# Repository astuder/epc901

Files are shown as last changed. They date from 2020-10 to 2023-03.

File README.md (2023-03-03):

# Introduction
The [ESPROS epc901](https://www.espros.com/photonics/epc901/) is a CCD line sensor with a resolution of 1024 monochrome pixels.

Compared to other image sensors the epc901 is very easy to drive, requiring only one voltage, I2C, a few digital I/Os and an ADC. It is also available for [$33 in single units from Digi-key](https://www.digikey.com/en/products/detail/espros-photonics-ag/EPC901-CSP32-033/10516882). On the downside, the sensor
comes in a BGA package, the evaluation kit is [very expensive at $1400](https://www.digikey.com/en/products/detail/espros-photonics-ag/EPC901-EVALUATION-KIT-V1/10516848),
and we haven't seen this sensor from any other distributors than Digi-key.

This repository contains design files to build hardware and software to interact with the sensor. 

For Windows users, there's now also a [version of g3gg0.de SpectrumPlotter](https://github.com/astuder/epc901SpectrumPlotter) adapted to work with my epc901 firmware.

@fmilburn3 posted a write-up of this project and a few spectroscopy experiments on [element14](https://www.element14.com/community/community/project14/sensors/blog/2020/11/11/spectrography-using-the-epc901-high-speed-line-image-sensor).

## Table of contents

[Hardware](#hardware)
* [Breakout board](#breakout-board)
  * [Connector pinout](#connector-pinout)
  * [Jumpers](#jumpers)
  * [Config resistor array](#config-resistor-array)
  * [Physical dimensions](#physical-dimensions)
  * [Lens holder & lens](#lens-holder--lens)
* [Adapter board](#adapter-board)
  * [Pin mapping](#pin-mapping)
  * [Jumpers](#jumpers)
* [Shared](#shared)
* [Spectroscope tube](#spectroscope-tube)

[Software](#software)
* [Firmware](#firmware)
  * [Shell](#shell)
  * [Capture logic](#capture-logic)
  * [Trigger logic](#trigger-logic)
  * [Transfer format](#transfer-format)
* [Python](#python)
  * [epc901camera.py](#epc901camerapy)
  * [example scripts](#example-scripts)
 
[License](#license)

# Hardware

All hardware in this project is designed with KiCad version 5.1.6.

The hardware consists of a breakout board for the image sensor, and an adapter board for vertically mounting the breakout board on an ST Nulceo-144 development board.

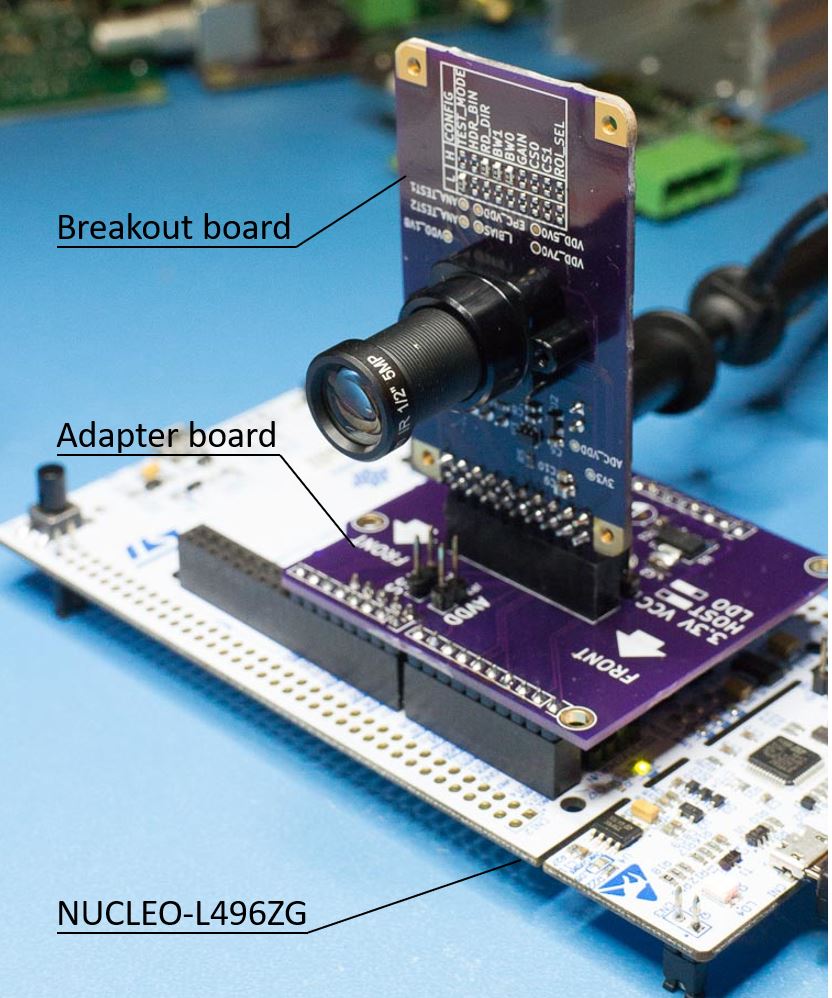
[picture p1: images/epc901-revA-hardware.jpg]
Breakout and adapter boards mounted on a NUCLEO L496ZG


## Breakout board

The folder [```./hardware/breakout```](./hardware/breakout) contains the KiCad project for the epc901 breakout board.

The image sensor comes in a 2x16, 0.5 mm pitch BGA package and looks very fragile. With careful handling and placement, we successfully assembled a few boards
using a stainless steel solder stencil and an unmodified toaster oven for reflow. Reflow on a hotplate probably works as well.

In addition to the image sensor and related passives, the breakout board also integrates an ADC. Footprint and firmware are compatible with [Texas Instruments ADCS7476](https://www.ti.com/product/ADCS7476) and [Analog Devices AD7476](https://www.analog.com/en/products/ad7476.html) which are 1 MSPS 12-bit ADCs with SPI-like interface.

The PCB can be ordered from OSH Park using this [link](https://oshpark.com/shared_projects/5eUl3QVW).

### Connector pinout

Pin|Function|Comment
-|-|-
1|GND|digital ground
2|PWR_DOWN|see epc901 datasheet
3|DATA_RDY|see epc901 datasheet
4|CLR_DATA|see epc901 datasheet
5|SHUTTER|see epc901 datasheet
6|CLR_PIX|see epc901 datasheet
7|GNDA|analog ground
8|VIDEO_P|positive video signal for use w/ external ADC, see epc901 datasheet
9|VIDEO_N|negative video signal for use w/ external ADC, see epc901 datasheet
10|GNDA|analog ground
11|GND|digital ground
12|ADC_CLK|SPI clk to on-board ADC
13|ADC_DATA|SPI data from on-board ADC
14|ADC_CS|SPI chip select for on-board ADC
15|GND|digital ground
16|3V3|3.3V power supply
17|GND|digital ground
18|READ|see epc901 datasheet
19|SDA|I2C data
20|SCL|I2C clock

### Jumpers

ID|Function|Comment
-|-|-
JP1|STAR GND|Star ground point between GND and GNDA. Close to connect, leave open if GNDA and GND are connected off-board.
JP2|ADC SELECTION|Selects whether to use the on-board ADC or an external ADC. External ADC will route VIDEO_P to pin 8 in the connector.

### Config resistor array

These resistors control the configuration of the image sensor on power-up. For details, see sections 4, 7.1 and 12 in the epc901 datasheet.

### Physical dimensions

The size of the board is 61 x 36 mm. The mounting holes in the corners are spaced 55 x 30 mm and have a diameter of 2.2 mm, designed for M2 screws.

The mounting holes for the lens holder are located 29 mm from the left board edge and 8 mm from top and bottom board edge. They have a diameter of 2.2 mm, designed for M2 screws.

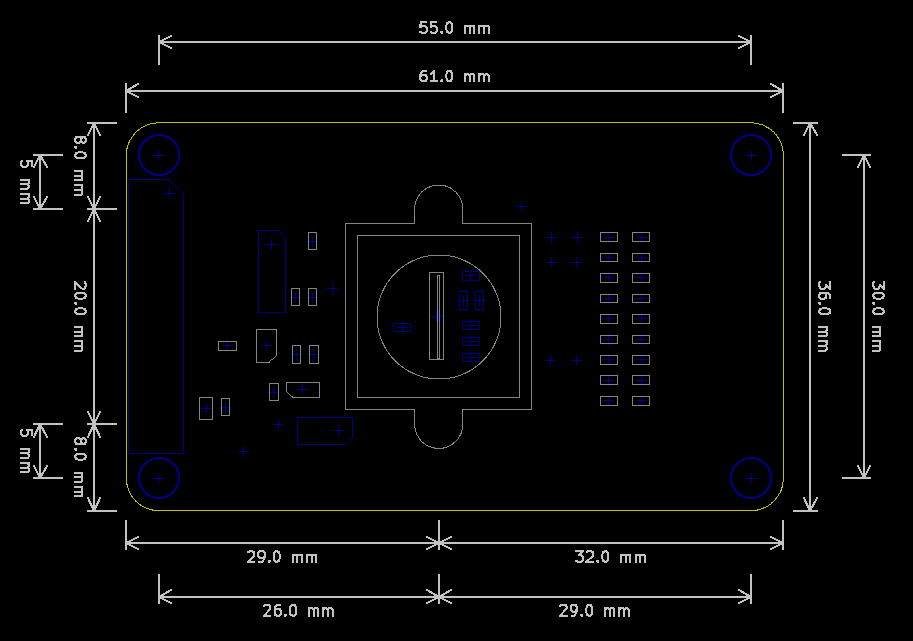
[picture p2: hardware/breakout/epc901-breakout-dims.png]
epc901-breakout dimensions


### Lens holder & lens

The breakout board has space and mounting holes for a lens holder. The spacing between the mounting holes is 20mm. For full coverage, the lens should support 1/2.3" or larger sensors.

For our prototypes, we chose a [M12 metal lens holder w/ 20mm hole spacing](https://www.m12lenses.com/CNC-Machined-M12-Lens-Holder-Metal-p/pt-lh031m.htm) and a [25mm M12 lens for 1/2" sensors](https://www.m12lenses.com/25mm-F2-4-5MP-CCTV-Lens-p/pt-2524mp5y.htm). In the US, a wide selection of lens holders and lenses can be found at [M12 Lenses Inc](https://www.m12lenses.com).

For use in a spectrograph, a lens may not be required. However we recommend protecting the sensor against accidental physical damage with some sort of bracket or baffel.

## Adapter board

The folder [```./hardware/adapter-shield```](./hardware/adapter-shield) contains the KiCad project for an adapter to mount the 
epc901 breakout board on the NUCLEO evaluation board.

The layout of the adapter board follows the Arduino Shield standard. This means you could mount the adapter and sensor breakout board on any compatible MCU board. Though
you will likely have to adapt the firmware to make it work.

The PCB can be ordered from OSH Park using this [link](https://oshpark.com/shared_projects/md99YXCX).

### Pin mapping

|Arduino|Nucleo|L496ZG|Breakout|Comment
|-|-|-|-|-
|+3V3|CN8 7|+3V3||Connected to JP1.
|+5V|CN8 9|+5V||Connected to 3.3V LDO.
|GND|CN8 11|GND|GND|
|GND|CN8 13|GND|GND|
|D0|CN10 16|PD9|PWR_DOWN|
|D1|CN10 14|PD8|DATA_RDY|
|D2|CN10 12|PF15|CLR_DATA|
|D3|CN10 10|PE13|SHUTTER|Controlled by TIM1_CH3.
|D4|CN10 8|PF14|CLR_PIX|
|D9|CN7 18|PD15|READ|
|D10|CN7 16|PD14|ADC_CS|
|D12/MISO|CN7 12|PA6|ADC_DATA|
|D13/SCK|CN7 10|PA5|ADC_CLK|
|GND|CN7 8|GND|GND|
|A0|CN9 1|PA3|VIDEO_P|
|A1|CN9 3|PC0|VIDEO_N|
||CN10 1|AVDD||Connected to JP3, reserved to supply analog power from Nucleo in future revisions.
||CN10 3|AVSS||Connected to JP4, alternative source for analog ground from Nucleo.
||CN10 5|GND|GND|
||CN10 7|PB1|VIDEO_P|Alternative analog pins for use with AVDD and AVSS connection in future revisions.
||CN10 9|PC2|VIDEO_N|Alternative analog pins for use with AVDD and AVSS connection in future revisions.

### Jumpers

ID|Function|Comment
-|-|-
JP1|3.3V VCC|Select between LDO on adapter or Nucleo (HOST) as source for 3.3V power supply to breakout board.
JP2|* GND|Star ground point between GND and GNDA. Close to connect, leave open if GNDA and GND are connected on breakout board.
JP3|AVDD|Reserved for future use to supply power to VDD_OA of the EPC901 from the Nucleo.
JP4|AVSS|Star ground point between analog ground of the breakout board and analog ground of the Nucleo. May be useful when using the ADCs of the STM32.

## Shared

The folder [```./hardware/shared```](./hardware/shared) contains custom KiCad symbols, footprints and 3d models that can be reused across KiCad projects in this repository.

## Spectroscope tube

For spectroscopy experiments we created a tube to mount an optical slit and difraction grating. The 3D model is available in the folder [```./hardware/spectroscope-tube```](./hardware/spectroscope-tube).

# Software

## Firmware

The folder [```./software/breakout```](./software/breakout) contains the firmware to control the epc901 breakout board with an
STM32L4 using the [NUCLEO-L496ZG evaluation board](https://www.digikey.com/en/products/detail/stmicroelectronics/NUCLEO-L496ZG/6697037). This specific MCU and
evaluation board were chosen because we had one laying around.

The firmware is developed and built with the latest version of STM32CubeIDE (version 1.4.2 as of October 2020). To import the project into STM32CubeIDE, clone this
repository, open STM32CubeIDE and import the project with ```File > Open Project From File System..```, and select the folder ```./software/breakout```. Follow the standard
procedure for building the firmware and programming the NUCLEO evaluation board.

### Shell

The firmware exposes a command shell over serial. The parameters of the serial connection are 115200 8N1.

Preceding a command with @ will suppress local echo and command prompt, which is useful when developing an application that interacts with the shell.

Most commands that configure an aspect of the firmware return the current setting if no value is provided. For example ```exposure``` will return the currently configured exposure time.

|Command|Description|
|-|-|
|help|Display list of available commands.|
|help COMMAND|Display help text for command.|
|echo ON/OFF|Turn local echo on or off.|
|regread REGISTER|Read register of image sensor over I2C.|
|regwrite REGISTER VALUE|Write to value to register of image sensor over I2C.|
|reset mcu|Reset the STM32 microcontroller.|
|reset camera|Reset the camera settings, for example exposure or burst, to their defaults.|
|reset sensor|Software reset of the image sensor through I2C.|
|exposure TIME_US|Set exposure time in microseconds.|
|exposure max|Get maximum exposure time supported.|
|capture|Start capture using the configured settings.|
|capture abort|If there's a capture in progress, abort current capture.|
|transfer|read next image from the frame buffer.|
|transfer all|read all images available in the frame buffer.|
|transfer last|read last image from frame buffer, all other images will be discarded.|
|burst ON/OFF|turn burst mode on or off.|
|burst fast|Turn on burst mode with fast capture, where image capture and data read out overlap. This can result in noisier data than regular burst mode.|
|burst frames COUNT|Set number of frames to capture in a burst.|
|burst interval TIME_MS|Set interval in milliseconds at which frames are captured. 0 will capture frames at the maximum speed possible.|
|trigger ON/OFF|Enable or disable trigger.|
|trigger source EXTERNAL/LEVEL/ZONE|Select source of trigger signal.|
|trigger direction RISING/FALLING|Set which direction of a signal will trigger. for ```level``` and ```zone``` rising means above/inside level/zone, falling means NOT above/inside.|
|trigger level LEVEL|Set trigger level for ```level``` trigger source.|
|trigger zone X1 Y1 X2 Y2|Set trigger zone defined by two corners for ```zone``` trigger source.|

### Capture logic

The ```capture``` command will start the image capture process based on the configuration of the camera.

First the firmware checks if there's enough space in the frame buffer for the configured number of frames (1 or burst frames). An error will be returned if there is not enoug space.

Next, if ```trigger``` is enabled, the camera waits until the configured trigger condition is met. 

Next, image capture starts. If ```burst``` is enabled, it will capture the configured number of frames. All frames captured are stored in a frame buffer. 

After the capture process is complete, images can be read from the frame buffer with the ```transfer``` command.

The shell will respond with ```BUSY``` if the camera is waiting for a trigger or a single image capture or burst is in progress. At any time, the command ```capture abort``` will return the camera back to idle state.

### Trigger logic

**External**

The external trigger source is wired to pin D35/PB11 and the USER button (B1).

Trigger direction ```rising``` triggers when the signal changes from low to high, or when the button is pressed down.
Trigger direction ```falling``` triggers when the signal changes from high to low, or when the button is released.

**Level**

The level trigger source uses live sensor data to trigger. When starting capture, the firmware will continously capture images until the trigger condition is met or capture is aborted.

Trigger direction ```rising``` triggers when a pixel is on or above the configured trigger level.
Trigger direction ```falling``` triggers when no pixel is on or above the configured trigger level.

**Zone**

The zone trigger source uses live sensor data to trigger. When starting capture, the firmware will continously capture images until the trigger condition is met or capture is aborted.

Trigger direction ```rising``` triggers when a pixel is inside the configured trigger zone.
Trigger direction ```falling``` triggers when no pixel is inside the configured trigger zone.

### Transfer format

The ```transfer``` command reads images from the frame buffer and sends them over serial. Each image is sent in two chuncks, each terminated with a linefeed. 

1. Frame metadata seperated with commas: frame number, time in milliseconds since first frame, exposure time in microseconds, number of pixels in frame
2. Frame data: a continous string with one 3-character hexadecimal number per pixel representing the brightness value

## Python

The folder [```./software/python```](./software/python) contains a Python library that wraps the shell of the
firmware, and a few useful Python scripts that use the library.

### epc901camera.py

The Python library ```epc901camera.py``` wraps the shell exposed by the firmware into an API that's easy to use from Python. 

```
from epc901camera import Camera
camera = Camera()
camera.open("my serial port")
camera.setExposure(1000)
camera.capture()
pixels = camera.getPixels()
camera.close()
```

You can use ```sendCommand()``` to directly interact with the shell, which can be useful for operations that are not supported by the library yet. The following snippet writes to I2C registers of the sensor to increase the gain.
```
camera.sendCommand("regwrite 2 0x99")  # turn on config via regs
camera.sendCommand("regwrite 0 0x19")  # 4x gain, read-out direction same as set by resistor
```

See [example scripts](#example-scripts) for more details.

### example scripts

There are three scripts to interact with the breakout board:
* ```live.py``` displays output of the image sensor in realtime
* ```snap.py``` captures one image
* ```burst.py``` captures a series of images in a burst

The scripts are controlled with shared and a few unique command line arguments.
|Argument|```live.py```|```snap.py```|```burst.py```|Description|
|-|-|-|-|-|
|-h, --help|:heavy_check_mark:|:heavy_check_mark:|:heavy_check_mark:|Display help text.|
|-p PORT|:heavy_check_mark:|:heavy_check_mark:|:heavy_check_mark:|Serial port which connects to the camera board, this is the only required argument.|
|-e EXPOSURE|:heavy_check_mark:|:heavy_check_mark:|:heavy_check_mark:|Set exposure time in microseconds. If not specified, the default exposure time is 1ms (1000us).|
|-t {external,level,zone}||:heavy_check_mark:|:heavy_check_mark:|Enable trigger and select trigger source. See [Trigger logic](#trigger-logic).|
|-tdir {falling,rising}||:heavy_check_mark:|:heavy_check_mark:|Set direction of trigger logic.|
|-tl TRIG_LEVEL||:heavy_check_mark:|:heavy_check_mark:|Set brightness for level trigger. Valid values are 0-4095.|
|-tz x1,y1,x2,y2||:heavy_check_mark:|:heavy_check_mark:|Define rectangle for zone trigger. Valid x values are 0-1023, valid y values are 0-4095.|
|-td TRIG_DELAY||:heavy_check_mark:|:heavy_check_mark:|Set delay in milliseconds after trigger event before image capture starts.|
|-f FRAMES|||:heavy_check_mark:|Number of frames to capture in a burst.|
|-i INTERVAL|||:heavy_check_mark:|Set time interval in milliseconds between frames. 0 means best effort, i.e. at maximum speed possible. As it takes 1.3ms to read out a frame, effective capture rates may be lower than the configured interval. |
|-fast|||:heavy_check_mark:|Enable special burst mode where frames are read out of the sensor while the next exposure is captured. This may increase noise, but will increase effective burst speeds.|
|-gq||:heavy_check_mark:|:heavy_check_mark:|Don't display graph window.|
|-g GRAPH_TYPE|||:heavy_check_mark:|Display animated 2D graph or 3D surface plot. If argument is missing, no graph will be displayed.|
|-gc COLOR|||:heavy_check_mark:|Select alternative color map for 3D graph.|
|-gpng GRAPH_FILE||:heavy_check_mark:|:heavy_check_mark:|Save graph as PNG file.|
|-png PNG_FILE||:heavy_check_mark:|:heavy_check_mark:|Save sensor data as a gray-scale bitmap in a PNG file.|
|-csv CSV_FILE||:heavy_check_mark:|:heavy_check_mark:|Save sensor data as CSV file.|
|-a|:heavy_check_mark:|:heavy_check_mark:|:heavy_check_mark:|Automatically scale vertical axis of graphs based on image data. If not specified, the Y axis will go from 0 to 3000.|
|-sx px1,w1,px2,w2|:heavy_check_mark:|:heavy_check_mark:|:heavy_check_mark:|Scale labels of horizontal axis of 2D graphs by linear interpolation based on two points, for example to reflect wavelengths in a spectrograph. If not specified, the X axis will be labelled with pixel positions 0-1024.|

# License

Unless stated otherwise, all software in this project is licensed under the terms of MIT License.

The main exception are files imported from the STM32 SDK ([```./software/breakout/Drivers```](./software/breakout/Drivers)), and a few files
auto-generated by STM32CubeIDE. See source code for applicable license terms.

All hardware in this project is licensed under the terms of CERN Open Hardware Licence Version 2 - Permissive.

See [LICENSE-SW](LICENSE-SW) and [LICENSE-HW](LICENSE-HW) for additional details.

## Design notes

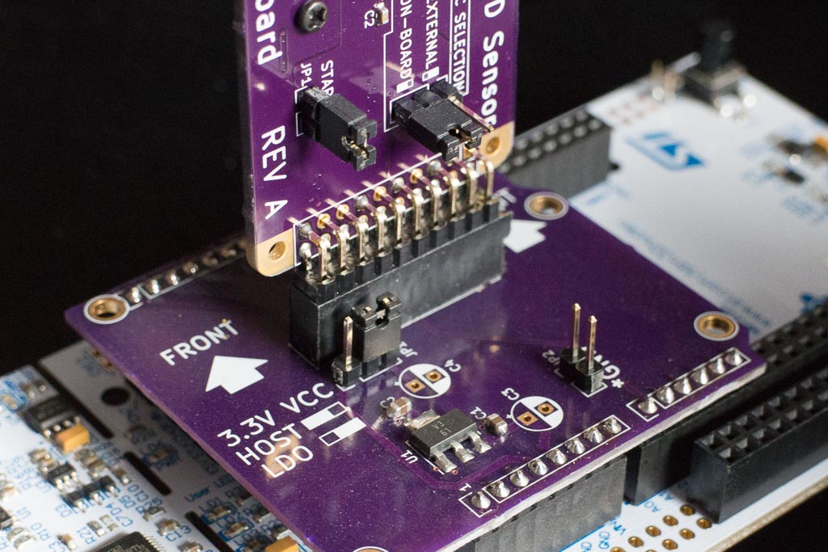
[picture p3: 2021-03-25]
images/epc901-revA-hardware-rear.jpg

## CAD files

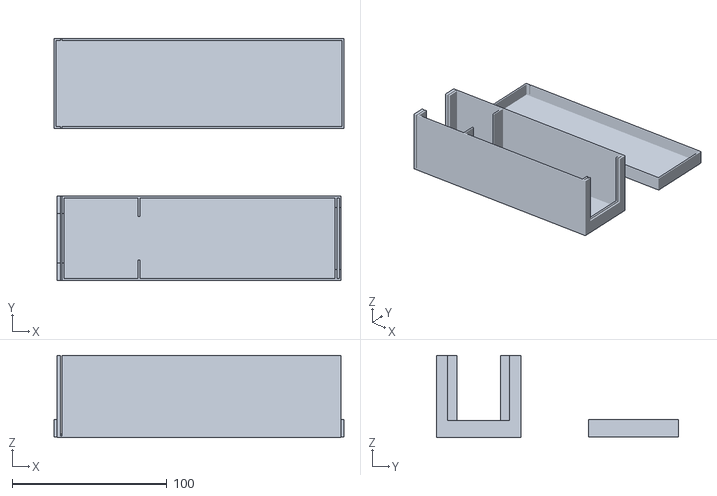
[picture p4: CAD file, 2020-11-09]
hardware/spectroscope-tube/Spectroscope_Tube_180mm.stl
187.2 x 156.2 x 53.2

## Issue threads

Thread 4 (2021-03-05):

Question convert to teensy and bbb

evermore99, 2021-03-05:
Hello first of all thanks for such a great project!

looking forward to replicate!

however I had a question: how hard is it to replace the nucleo with a teensy4.0? it runs way faster, is there a way you could come in contact with me?

i believe the bbb allows for python to run on it.

Could you send Me an email?

 Many thanks!

astuder, 2021-03-05:
Thanks for your interest in my project :)

Porting to the Teensy would require to rewrite the code that interacts with the STM32 HAL and hardware registers. Most of that is contained in EPC901.cpp, Leds.cpp, ShellPlatform.cpp and main.c. More work may be required if you want to integrate with the Teensy Arduino framework.

The speed of the MCU is not the limiting factor in this project. The ADC I used has a sampling rate of 10 MSPS, which translates to roughly 1000 fps maximum frame rate. For a higher speed version of the circuit see this project:
https://github.com/gregdavill/advent-calendar-of-circuits-2020/tree/main/syzygy-epc901
Though I don't think Greg started on the software (FPGA) side yet.

You can find my email address on my Github profile page.

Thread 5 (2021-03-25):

Question about jumpers

Sam2R, 2021-03-25:
Hi astuder,
First I wanted to thank you for your amazing work in this project. I had a question about the adapter shield. in your photo of the board I can see that you did not mount C3 and C4 capacitors on the shield so that means 5v connection on the board is ignored. Is that ok to use the board like you did (not mounting C3/C4 on shield and connect pins 1&2 on JP1 )?
in general, that would be helpful if you could mention default jumper connections on breakout and shield .
I appreciate very much your help on this and thanks again!

astuder, 2021-03-25:
Always happy when my projects are of interest to someone :)

I added the footprints for bigger caps just in case. The 5V LDO works fine with just the 1uF caps. I did only briefly check that the camera works when powered from 3V3 or 5V, but never investigated in depth whether one or the other is better, or whether more power supply filtering is needed.

I just uploaded an image showing the back side of the shield.
https://github.com/astuder/epc901/blob/main/images/epc901-revA-hardware-rear.jpg

astuder, 2021-03-25:
Clarification: I meant HOST (i.e. 3.3V from the Nucleo board) or LDO (i.e. 5V from the Nucleo down-converted to 3.3V)

Sam2R, 2021-03-25:
That's cool! Thanks, I'm happy you are  there I can ask my questions  👍
Wish me lock by the way I'm going to reflow/solder this tiny fragile EPC901 :)

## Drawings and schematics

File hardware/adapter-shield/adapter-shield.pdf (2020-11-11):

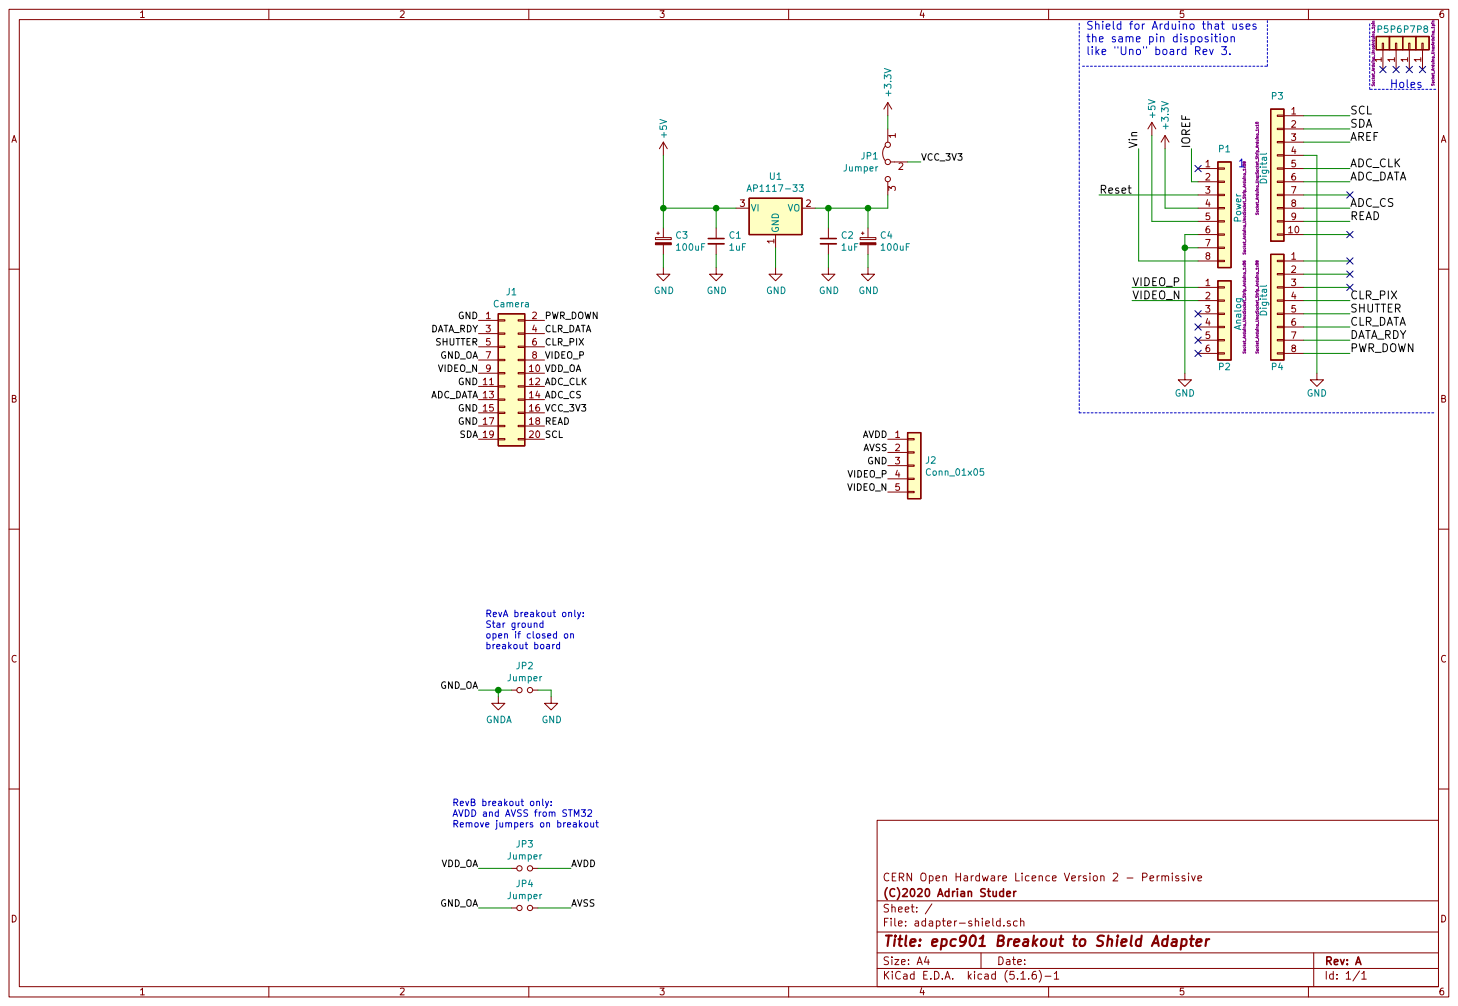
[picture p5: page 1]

Shield for Arduino that uses
the same pin disposition
VCC_3V3 VIDEO_N

Star ground
open if closed on
breakout board RevB breakout only: AVDD and AVSS from STM32 Remove jumpers on breakout
VDD_OA GND_OA GND_OA

Jumper
CERN Open Hardware Licence Version 2 - Permissive JP4

File: adapter-shield.sch Sheet: / (C)2020 Adrian Studer

Id: 1/1 Title: epc901 Breakout to Shield Adapter

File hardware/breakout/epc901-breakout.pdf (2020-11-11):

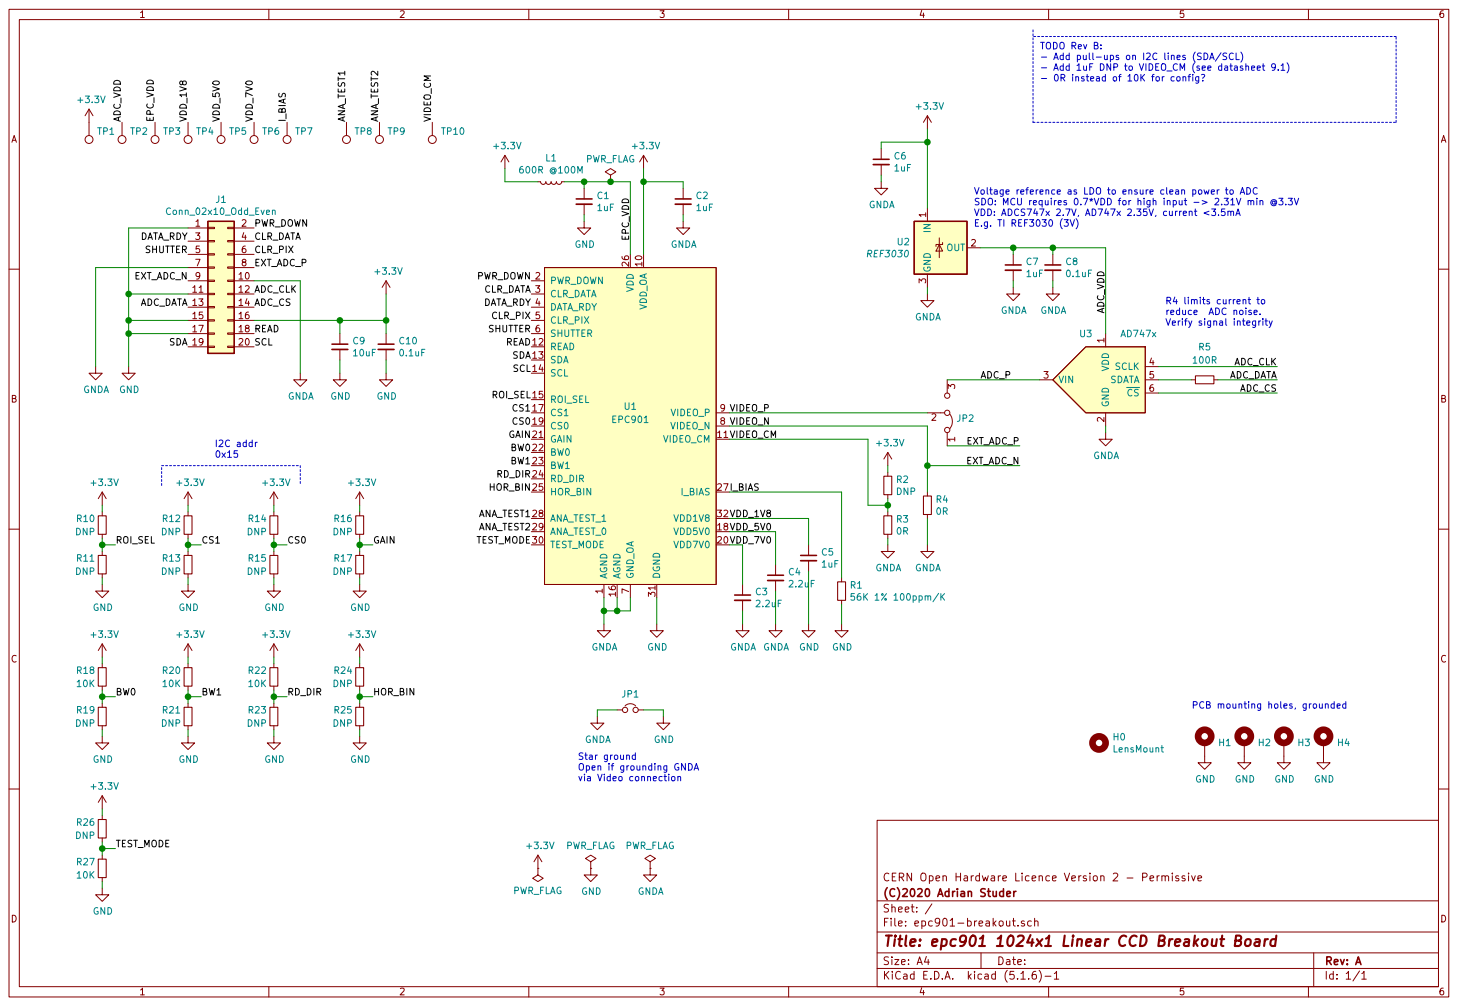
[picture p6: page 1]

TODO Rev B: - Add pull-ups on I2C lines (SDA/SCL)

- Add 1uF DNP to VIDEO_CM (see datasheet 9.1)
- 0R instead of 10K for config?

SDO: MCU requires 0.7*VDD for high input -> 2.31V min @3.3V
VDD: ADCS747x 2.7V, AD747x 2.35V, current <3.5mA
E.g. TI REF3030 (3V)

1 VDD_OA 10 VIDEO_CM 11 READ 12 SDA 13 SCL 14 ROI_SEL 15 AGND 16 CS1 17 VDD5V0 18 CS0 19 PWR_DOWN 2 VDD7V0 20 GAIN 21 BW0 22 BW1 23 RD_DIR 24 HOR_BIN 25 VDD 26

reduce ADC noise. Verify signal integrity

17 | 18
19 | 20

2 VIN 3 SCLK 4 SDATA 5 CS 6 U3 AD747x R4

PCB mounting holes, grounded

Star ground
Open if grounding GNDA
via Video connection

File: epc901-breakout.sch Sheet: / (C)2020 Adrian Studer

Id: 1/1 Title: epc901 1024x1 Linear CCD Breakout Board

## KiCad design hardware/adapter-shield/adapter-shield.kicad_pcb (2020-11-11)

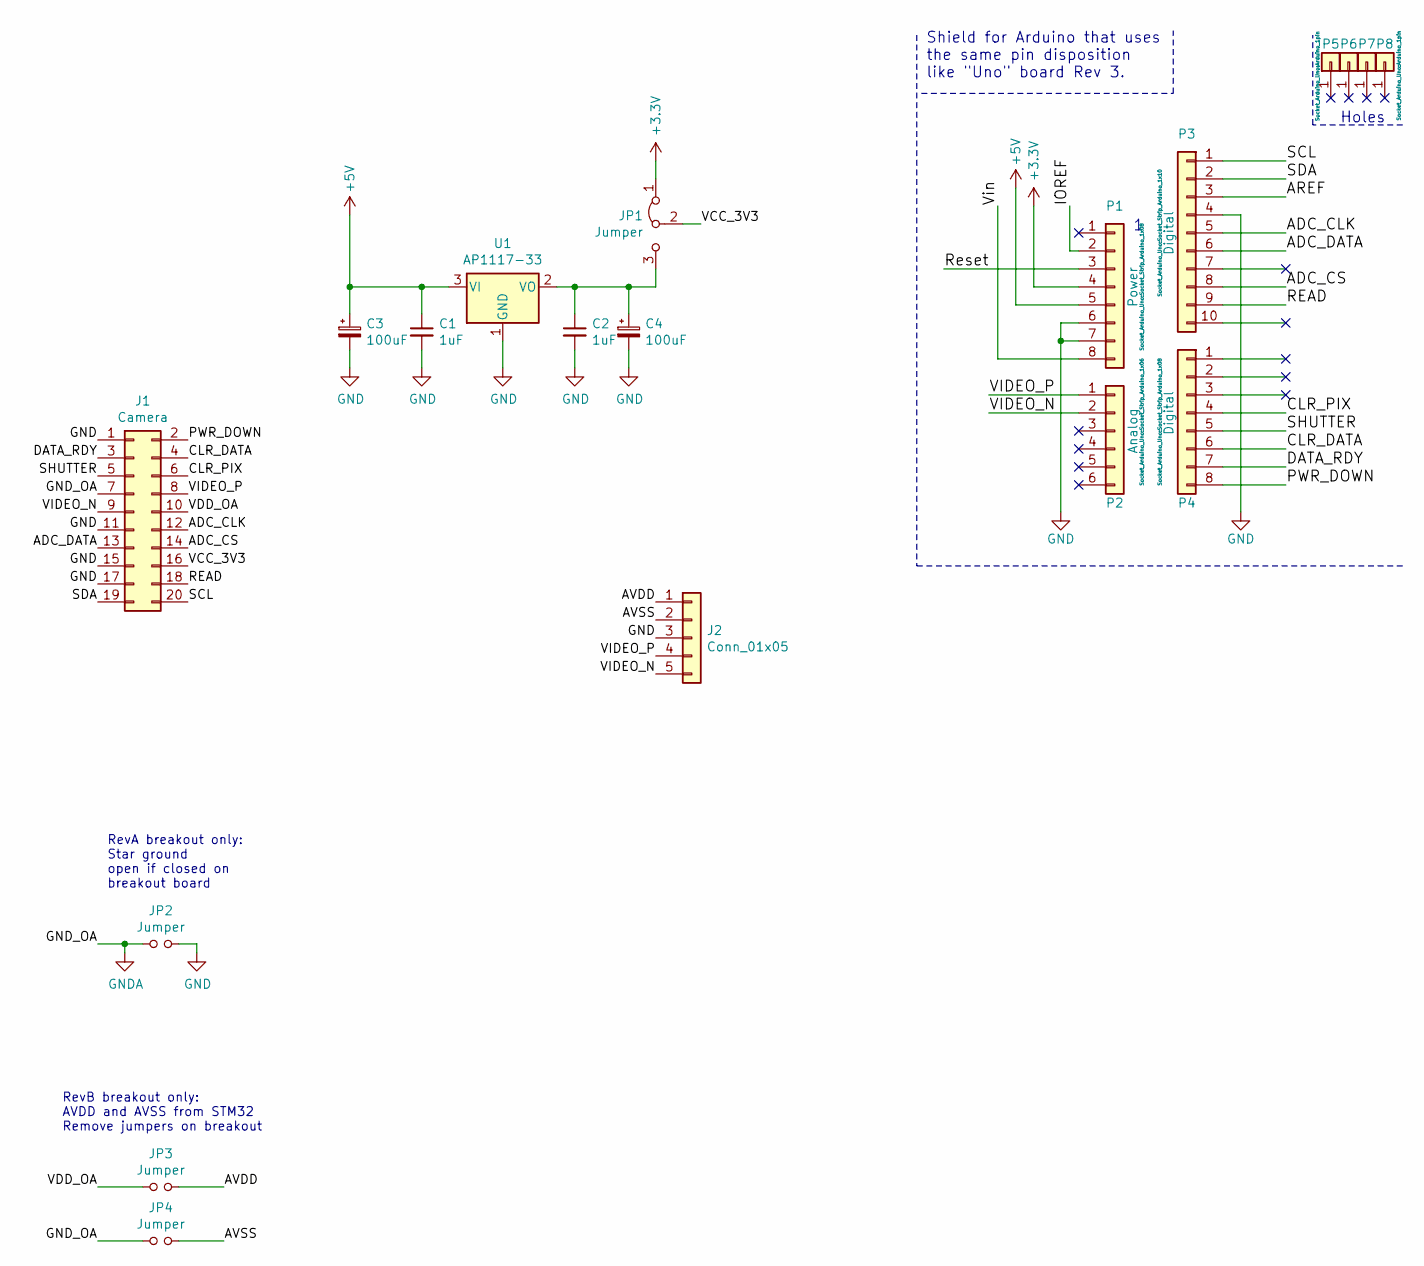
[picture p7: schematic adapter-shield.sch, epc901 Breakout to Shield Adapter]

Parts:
C1, C2: 1uF; C_0805_2012Metric
C3, C4: 100uF; CP_Radial_D5.0mm_P2.50mm
J1: Camera; PinSocket_2x10_P2.54mm_Vertical
J2: Conn_01x05; PinHeader_1x05_P2.54mm_Vertical
JP1: Jumper; PinHeader_1x03_P2.54mm_Vertical
JP2, JP3, JP4: Jumper; PinHeader_1x02_P2.54mm_Vertical
P1: Power; Socket_Strip_Arduino_1x08
P2: Analog; Socket_Strip_Arduino_1x06
P3: Digital; Socket_Strip_Arduino_1x10
P4: Digital; Socket_Strip_Arduino_1x08
P5, P6, P7, P8: CONN_01X01; Arduino_1pin
U1: AP1117-33; SOT-223-3_TabPin2

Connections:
+3V3: JP1.1 (A), P1.4
+5V: C1.1, C3.1, P1.5, U1.3 (VI)
/ADC_CLK: J1.12, P3.5
/ADC_CS: J1.14, P3.8
/ADC_DATA: J1.13, P3.6
/AREF: P3.3
/AVDD: J2.1, JP3.2
/AVSS: J2.2, JP4.2
/CLR_DATA: J1.4, P4.6
/CLR_PIX: J1.6, P4.4
/DATA_RDY: J1.3, P4.7
/IOREF: P1.2
/PWR_DOWN: J1.2, P4.8
/READ: J1.18, P3.9
/Reset: P1.3
/SCL: J1.20, P3.1
/SDA: J1.19, P3.2
/SHUTTER: J1.5, P4.5
/VCC_3V3: J1.16, JP1.2 (C)
/VDD_OA: J1.10, JP3.1
/VIDEO_N: J1.9, J2.5, P2.2
/VIDEO_P: J1.8, J2.4, P2.1
/Vin: P1.8
GND: C1.2, C2.2, C3.2, C4.2, J1.1, J1.11, J1.15, J1.17, J2.3, JP2.2, P1.6, P1.7, P3.4, U1.1 (GND)
GNDA: J1.7, JP2.1, JP4.1
unnamed: C2.1, C4.1, JP1.3 (B), U1.2 (VO)

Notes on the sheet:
Holes
Shield for Arduino that uses the same pin disposition like "Uno" board Rev 3.
RevA breakout only: Star ground open if closed on breakout board
RevB breakout only: AVDD and AVSS from STM32 Remove jumpers on breakout

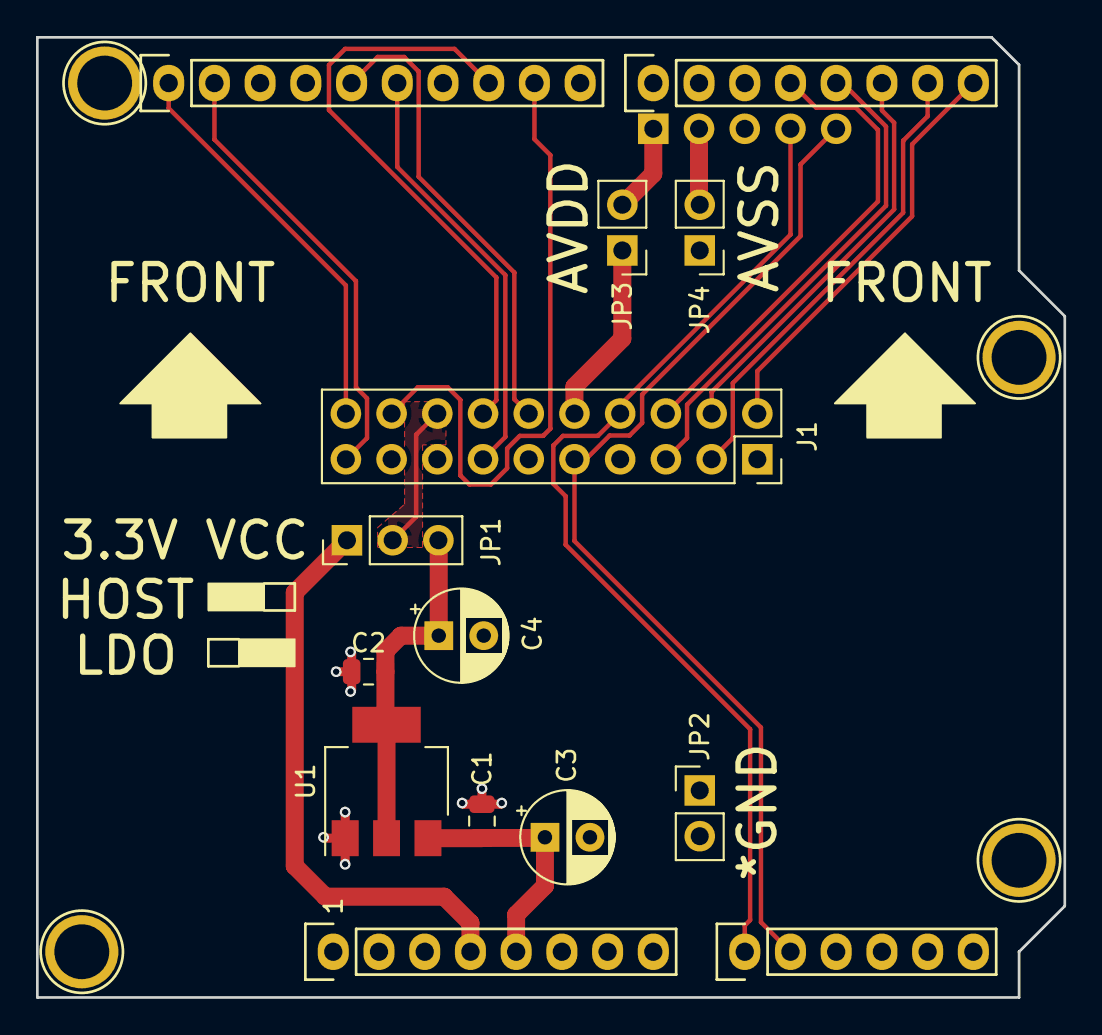
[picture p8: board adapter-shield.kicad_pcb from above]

Board: 2 copper layers, 57.1 x 53.3 mm, 19 parts (1 on the bottom side), 22 nets.

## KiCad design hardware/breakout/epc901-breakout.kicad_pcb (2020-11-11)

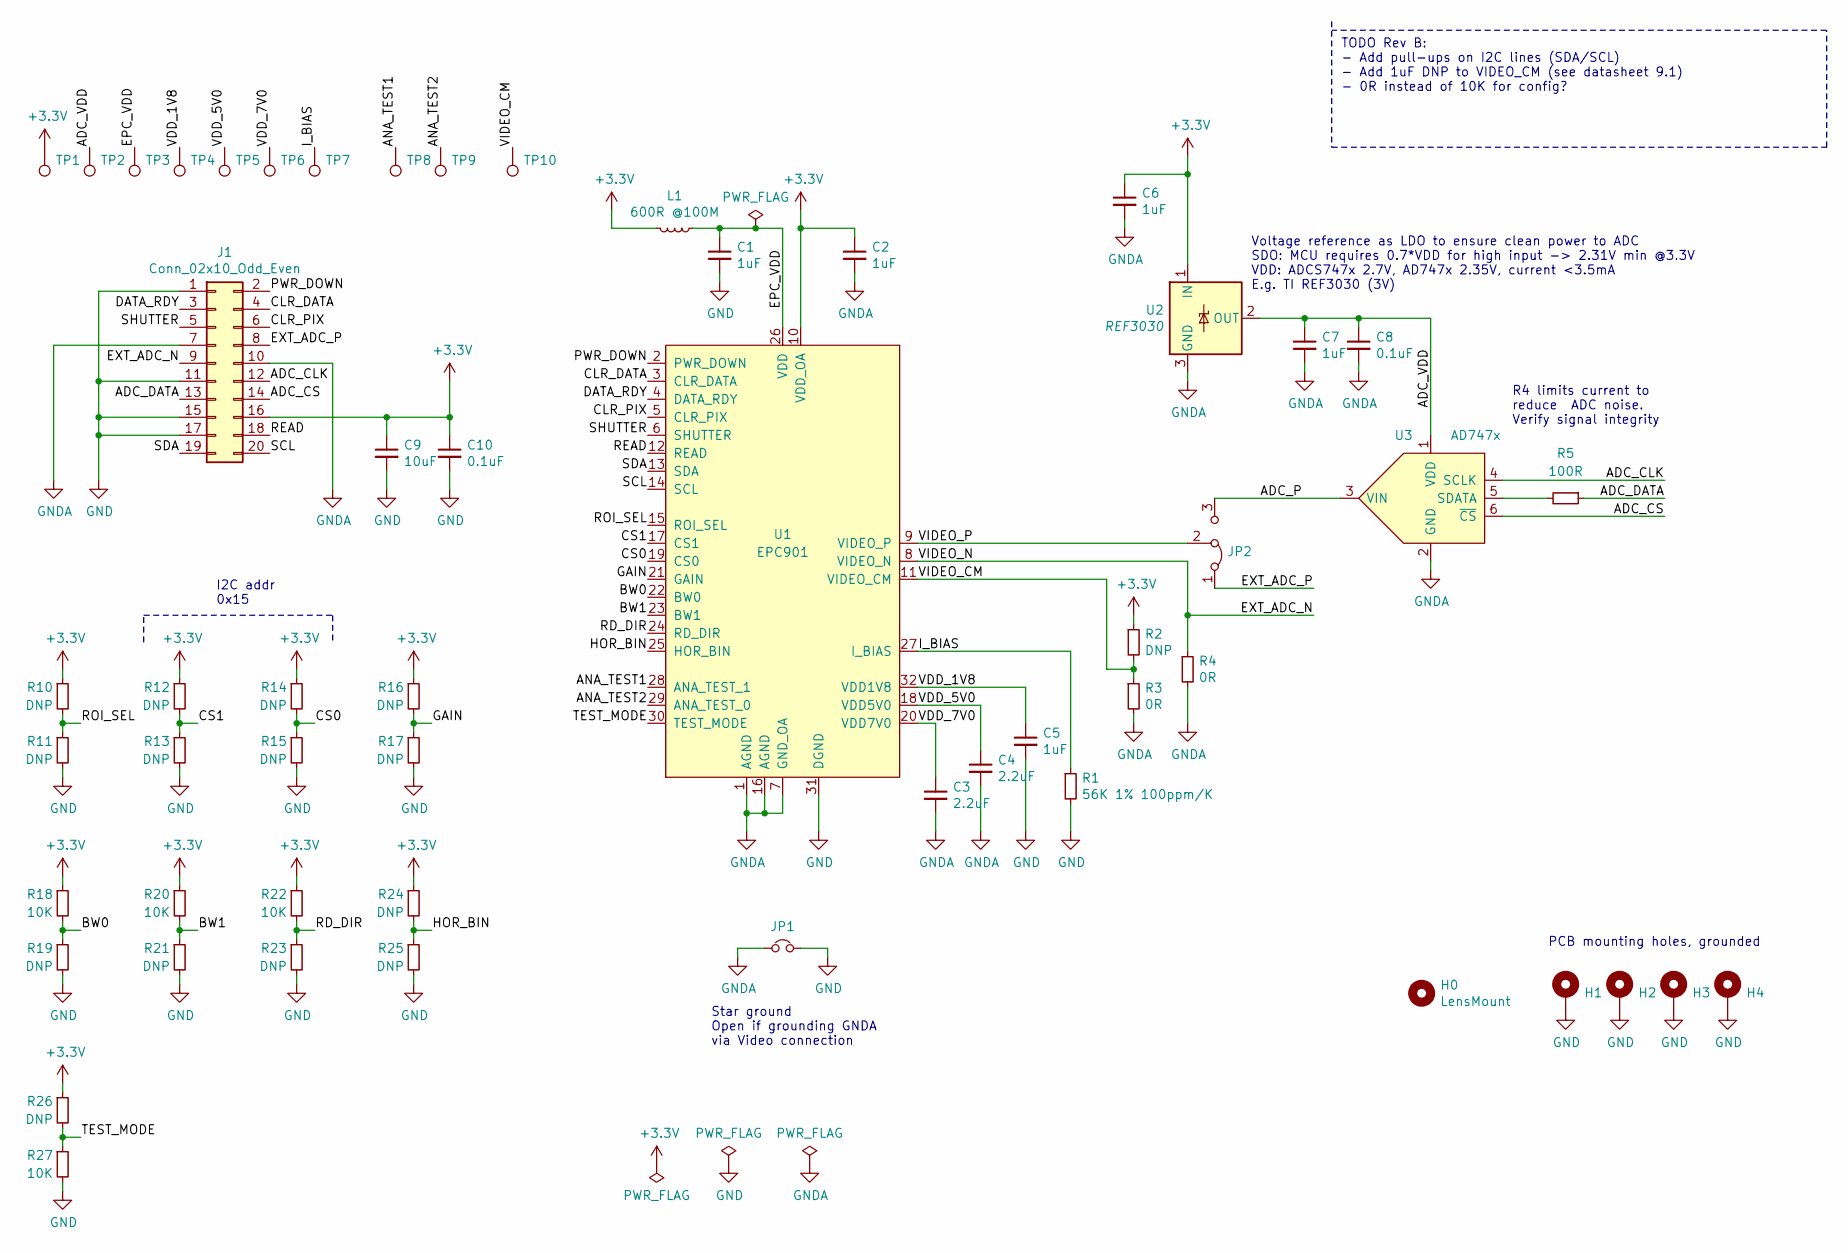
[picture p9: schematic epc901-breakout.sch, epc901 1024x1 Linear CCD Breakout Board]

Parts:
C1, C2, C5, C6, C7: 1uF; C_0603_1608Metric
C3, C4: 2.2uF; C_0603_1608Metric
C8, C10: 0.1uF; C_0603_1608Metric
C9: 10uF; C_0805_2012Metric
H0: LensMount; lensholder-m12-20mm
H1, H2, H3, H4: MountingHole_Pad; MountingHole_2.2mm_M2_DIN965_Pad
J1: Conn_02x10_Odd_Even; PinHeader_2x10_P2.54mm_Vertical
JP1: Jumper_NC_Small; PinHeader_1x02_P2.54mm_Vertical
JP2: Jumper_3_Bridged12; PinHeader_1x03_P2.54mm_Vertical
L1: 600R @100M; L_0603_1608Metric; Mpn BLM18TG601TN1D
R1: 56K 1% 100ppm/K; R_0603_1608Metric
R2, R10, R11, R12, R13, R14, R15, R16, R17, R19, R21, R23, R24, R25, R26: DNP; R_0603_1608Metric
R3, R4: 0R; R_0603_1608Metric
R5: 100R; R_0603_1608Metric
R18, R20, R22, R27: 10K; R_0603_1608Metric
TP1, TP2, TP3, TP4, TP5, TP6, TP7, TP8, TP9, TP10: TestPoint; TestPoint_Pad_D1.0mm
U1: EPC901; epc901; Mpn EPC901-CSP32-033
U2: REF3030; SOT-23; Mpn REF3030AIDBZR
U3: AD747x; SOT-23-6; Mpn ADCS7476AIMF/NOPB‎

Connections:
+3V3: C2.1, C6.1, C9.1, C10.1, J1.16, L1.2, R2.1, R10.1, R12.1, R14.1, R16.1, R18.1, R20.1, R22.1, R24.1, R26.1, TP1.1, U1.10 (VDD_OA), U2.1 (IN)
/ADC_CLK: J1.12, U3.4 (SCLK)
/ADC_CS: J1.14, U3.6 (~CS)
/ADC_DATA: J1.13, R5.1
/ADC_P: JP2.3 (B), U3.3 (VIN)
/ADC_VDD: C7.1, C8.1, TP2.1, U2.2 (OUT), U3.1 (VDD)
/ANA_TEST1: TP8.1, U1.28 (ANA_TEST_1)
/ANA_TEST2: TP9.1, U1.29 (ANA_TEST_0)
/BW0: R18.2, R19.1, U1.22 (BW0)
/BW1: R20.2, R21.1, U1.23 (BW1)
/CLR_DATA: J1.4, U1.3 (CLR_DATA)
/CLR_PIX: J1.6, U1.5 (CLR_PIX)
/CS0: R14.2, R15.1, U1.19 (CS0)
/CS1: R12.2, R13.1, U1.17 (CS1)
/DATA_RDY: J1.3, U1.4 (DATA_RDY)
/EPC_VDD: C1.1, L1.1, TP3.1, U1.26 (VDD)
/EXT_ADC_N: J1.9, R4.1, U1.8 (VIDEO_N)
/EXT_ADC_P: J1.8, JP2.1 (A)
/GAIN: R16.2, R17.1, U1.21 (GAIN)
/HOR_BIN: R24.2, R25.1, U1.25 (HOR_BIN)
/I_BIAS: R1.1, TP7.1, U1.27 (I_BIAS)
/PWR_DOWN: J1.2, U1.2 (PWR_DOWN)
/RD_DIR: R22.2, R23.1, U1.24 (RD_DIR)
/READ: J1.18, U1.12 (READ)
/ROI_SEL: R10.2, R11.1, U1.15 (ROI_SEL)
/SCL: J1.20, U1.14 (SCL)
/SDA: J1.19, U1.13 (SDA)
/SHUTTER: J1.5, U1.6 (SHUTTER)
/TEST_MODE: R26.2, R27.1, U1.30 (TEST_MODE)
/VDD_1V8: C5.1, TP4.1, U1.32 (VDD1V8)
/VDD_5V0: C4.1, TP5.1, U1.18 (VDD5V0)
/VDD_7V0: C3.1, TP6.1, U1.20 (VDD7V0)
/VIDEO_CM: R2.2, R3.1, TP10.1, U1.11 (VIDEO_CM)
/VIDEO_P: JP2.2 (C), U1.9 (VIDEO_P)
GND: C1.2, C5.2, C9.2, C10.2, H1.1, H2.1, H3.1, H4.1, J1.1, J1.11, J1.15, J1.17, JP1.2, R1.2, R11.2, R13.2, R15.2, R17.2, R19.2, R21.2, R23.2, R25.2, R27.2, U1.31 (DGND)
GNDA: C2.2, C3.2, C4.2, C6.2, C7.2, C8.2, J1.7, J1.10, JP1.1, R3.2, R4.2, U1.1 (AGND), U1.7 (GND_OA), U1.16 (AGND), U2.3 (GND), U3.2 (GND)
unnamed: R5.2, U3.5 (SDATA)

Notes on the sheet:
Voltage reference as LDO to ensure clean power to ADC SDO: MCU requires 0.7*VDD for high input -> 2.31V min @3.3V VDD: ADCS747x 2.7V, AD747x 2.35V, current <3.5mA E.g. TI REF3030 (3V)
I2C addr 0x15
PCB mounting holes, grounded
R4 limits current to reduce ADC noise. Verify signal integrity
Star ground Open if grounding GNDA via Video connection
TODO Rev B: - Add pull-ups on I2C lines (SDA/SCL) - Add 1uF DNP to VIDEO_CM (see datasheet 9.1) - 0R instead of 10K for config?

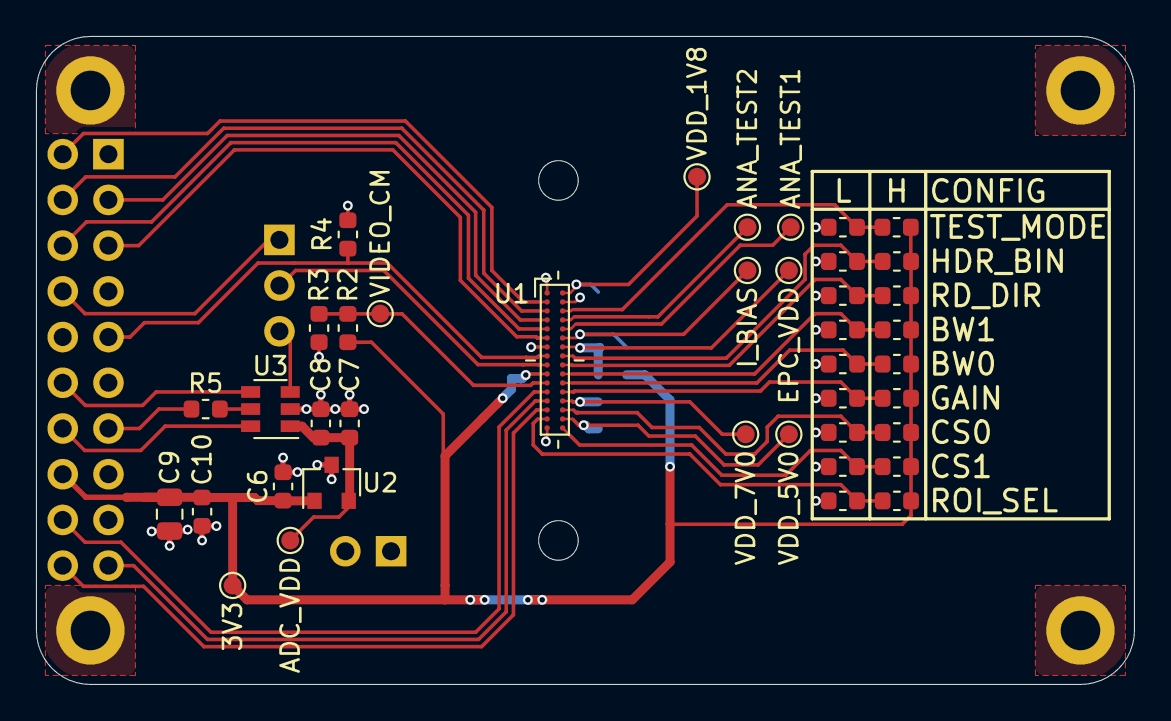
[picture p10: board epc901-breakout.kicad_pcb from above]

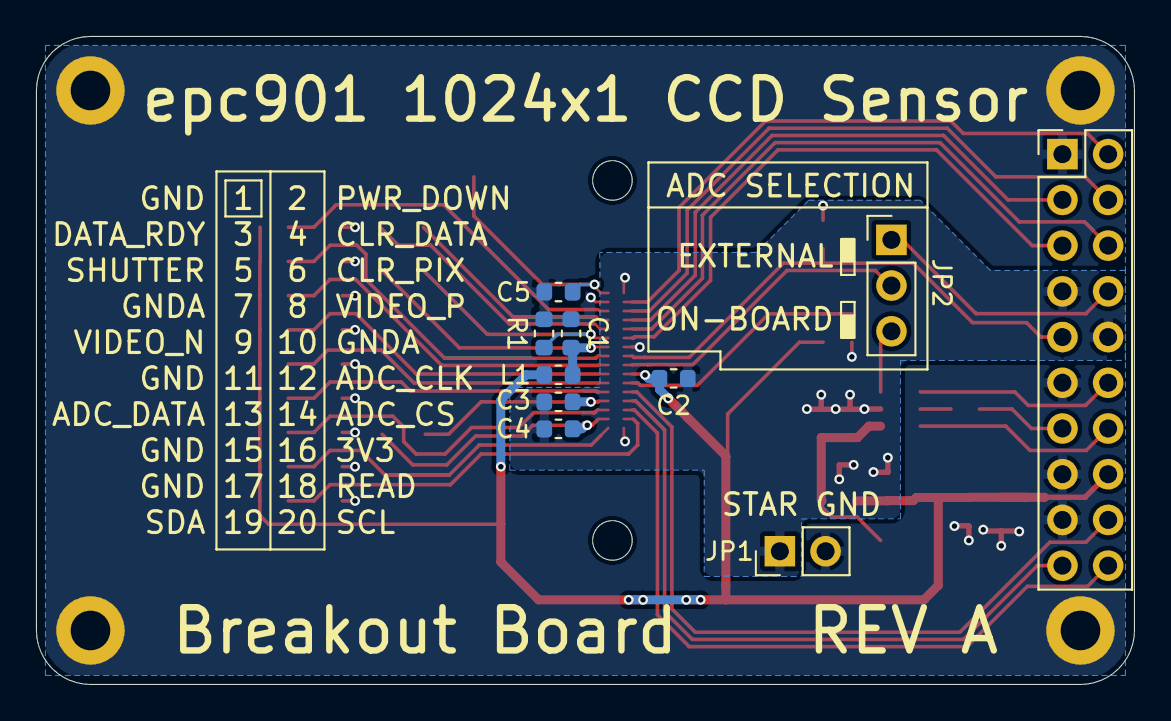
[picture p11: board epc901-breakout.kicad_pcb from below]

Board: 2 copper layers, 61.0 x 36.0 mm, 55 parts (10 on the bottom side), 37 nets.

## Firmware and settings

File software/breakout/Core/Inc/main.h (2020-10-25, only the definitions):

#define B1_Pin GPIO_PIN_13
#define B1_GPIO_Port GPIOC
#define B1_EXTI_IRQn EXTI15_10_IRQn
#define ADC_CLK_Pin GPIO_PIN_5
#define ADC_CLK_GPIO_Port GPIOA
#define ADC_DATA_Pin GPIO_PIN_6
#define ADC_DATA_GPIO_Port GPIOA
#define CLR_PIX_Pin GPIO_PIN_14
#define CLR_PIX_GPIO_Port GPIOF
#define CLR_DATA_Pin GPIO_PIN_15
#define CLR_DATA_GPIO_Port GPIOF
#define SHUTTER_Pin GPIO_PIN_13
#define SHUTTER_GPIO_Port GPIOE
#define TRIGGER_Pin GPIO_PIN_11
#define TRIGGER_GPIO_Port GPIOB
#define TRIGGER_EXTI_IRQn EXTI15_10_IRQn
#define LD3_Pin GPIO_PIN_14
#define LD3_GPIO_Port GPIOB
#define DATA_RDY_Pin GPIO_PIN_8
#define DATA_RDY_GPIO_Port GPIOD
#define PWR_DOWN_Pin GPIO_PIN_9
#define PWR_DOWN_GPIO_Port GPIOD
#define ADC_CS_Pin GPIO_PIN_14
#define ADC_CS_GPIO_Port GPIOD
#define READ_Pin GPIO_PIN_15
#define READ_GPIO_Port GPIOD
#define USB_OverCurrent_Pin GPIO_PIN_5
#define USB_OverCurrent_GPIO_Port GPIOG
#define USB_PowerSwitchOn_Pin GPIO_PIN_6
#define USB_PowerSwitchOn_GPIO_Port GPIOG
#define STLK_RX_Pin GPIO_PIN_7
#define STLK_RX_GPIO_Port GPIOG
#define STLK_TX_Pin GPIO_PIN_8
#define STLK_TX_GPIO_Port GPIOG
#define LD1_Pin GPIO_PIN_7
#define LD1_GPIO_Port GPIOC
#define USB_SOF_Pin GPIO_PIN_8
#define USB_SOF_GPIO_Port GPIOA
#define USB_VBUS_Pin GPIO_PIN_9
#define USB_VBUS_GPIO_Port GPIOA
#define USB_ID_Pin GPIO_PIN_10
#define USB_ID_GPIO_Port GPIOA
#define USB_DM_Pin GPIO_PIN_11
#define USB_DM_GPIO_Port GPIOA
#define USB_DP_Pin GPIO_PIN_12
#define USB_DP_GPIO_Port GPIOA
#define TMS_Pin GPIO_PIN_13
#define TMS_GPIO_Port GPIOA
#define TCK_Pin GPIO_PIN_14
#define TCK_GPIO_Port GPIOA
#define SWO_Pin GPIO_PIN_3
#define SWO_GPIO_Port GPIOB
#define LD2_Pin GPIO_PIN_7
#define LD2_GPIO_Port GPIOB
#define I2C_SCL_Pin GPIO_PIN_8
#define I2C_SCL_GPIO_Port GPIOB
#define I2C_SDA_Pin GPIO_PIN_9
#define I2C_SDA_GPIO_Port GPIOB

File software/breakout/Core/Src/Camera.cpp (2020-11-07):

/*
 * Camera application logic.
 *
 * Copyright 2020 by Adrian Studer
 *
 * Licensed under the terms of MIT License, all text here must be included in any redistribution.
 * See the LICENSE-SW file for details.
 */

#include "main.h"
#include "Camera.hpp"
#include "EPC901.hpp"
#include "Leds.hpp"
#include "Shell.hpp"
#include "CmdExposure.hpp"
#include "CmdCapture.hpp"
#include "CmdTransfer.hpp"
#include "CmdBurst.hpp"
#include "CmdTrigger.hpp"
#include <cstring>

Frame::Frame() {
	number = 0;
	timestamp = 0;
	exposure_time = 0;
	memset(pixels, 0, sizeof(pixels));
}

Camera::Camera() {
	_sensor = 0;
	_frame_buffer = 0;
	reset();
}

void Camera::reset(void) {
	// set sensible defaults
	_state = ST_IDLE;
	_exposure_time = 25;
	_burst_enable = 0;
	_burst_fast = 0;
	_burst_interval = 0;
	_burst_frames = 2;
	_trigger_enable = 0;
	_trigger_source = TRIG_EXTERNAL;
	_trigger_delay = 0;
	_trigger_direction = TRIG_RISING;
	_trigger_level = 1500;
	_external_trigger = 0;
	memset(&_trigger_zone, 0, sizeof(trig_zone_t));
}

void Camera::init(EPC901 *sensor, Shell *shell, Frame* frame_buffer, uint16_t frame_buf_size) {
	_sensor = sensor;

	// register camera commands with shell
	if (shell) {
		static CmdExposure cmd_exposure(this);
		shell->registerCmd(&cmd_exposure);
		static CmdCapture cmd_capture(this);
		shell->registerCmd(&cmd_capture);
		static CmdTransfer cmd_transfer(this);
		shell->registerCmd(&cmd_transfer);
		static CmdBurst cmd_burst(this);
		shell->registerCmd(&cmd_burst);
		static CmdTrigger cmd_trigger(this);
		shell->registerCmd(&cmd_trigger);
	}

	// setup frame buffer
	// we need space for at least 1 frame, may be extended later for functionality like HDR
	if (frame_buffer && frame_buf_size) {
		_frame_buffer = frame_buffer;
		_frame_buf_size = frame_buf_size;
	} else {
		_frame_buffer = 0;
		_frame_buf_size = 0;
	}
	_frame_read = 0;
	_frame_write = 0;
	_frame_count = 0;
}

void Camera::loop(void) {
	switch (_state) {
	case ST_IDLE:
		break;
	case ST_CAPTURE:
		_captureLoop();
		break;
	case ST_CAPTURE_FAST:
		_captureLoopFast();
		break;
	case ST_TRIGGER:
		_triggerLoop();
		break;
	case ST_TRIGGER_DELAY:
		_triggerDelayLoop();
		break;
	default:
		_state = ST_IDLE;
		break;
	}

	return;
}

Camera::state_t Camera::getState(void) {
	return _state;
}

void Camera::setExposureTime(uint32_t time_us) {
	if (time_us == 0) {
		// TODO: determine exposure automatically
	} else {
		if (time_us > 0 && time_us <= EPC901::getMaxExposure()) {
			_exposure_time = time_us;
		} else {
			// ignore invalid values
		}
	}
}

uint32_t Camera::getExposureTime(void) {
	return _exposure_time;
}

uint32_t Camera::getMaxExposureTime(void) {
	return EPC901::getMaxExposure();
}

void Camera::setBurstEnable(uint8_t enable) {
	if (0 == enable) {
		_burst_enable = 0;
	} else {
		_burst_enable = 1;
	}
}

uint8_t Camera::getBurstEnable(void) {
	return _burst_enable;
}

void Camera::setBurstFast(uint8_t fast) {
	if (0 == fast) {
		_burst_fast = 0;
	} else {
		_burst_fast = 1;
	}
}

uint8_t Camera::getBurstFast(void) {
	return _burst_fast;
}

void Camera::setBurstFrames(uint16_t frames) {
	if (frames > _frame_buf_size) {
		_burst_frames = _frame_buf_size;
	} else {
		_burst_frames = frames;
	}
}

uint16_t Camera::getBurstFrames(void) {
	return _burst_frames;
}

void Camera::setBurstInterval(uint16_t interval) {
	_burst_interval = interval;
}

uint16_t Camera::getBurstInterval(void) {
	return _burst_interval;
}

void Camera::setTriggerEnable(uint8_t enable) {
	if (0 == enable) {
		_trigger_enable = 0;
	} else {
		_trigger_enable = 1;
	}
}

uint8_t Camera::getTriggerEnable(void) {
	return _trigger_enable;
}

void Camera::setTriggerSource(trig_src_t source) {
	_trigger_source = source;
}

Camera::trig_src_t Camera::getTriggerSource(void) {
	return _trigger_source;
}

void Camera::setTriggerDelay(uint16_t delay) {
	_trigger_delay = delay;
}

uint16_t Camera::getTriggerDelay(void) {
	return _trigger_delay;
}

void Camera::setTriggerDirection(trig_dir_t direction) {
	_trigger_direction = direction;
}

Camera::trig_dir_t Camera::getTriggerDirection(void) {
	return _trigger_direction;
}

void Camera::setTriggerLevel(uint16_t level) {
	_trigger_level = level;
}

uint16_t Camera::getTriggerLevel(void) {
	return _trigger_level;
}

void Camera::setTriggerZone(trig_zone_t zone) {
	if (zone.x1 >= 1024 || zone.x2 >= 1024 ||
		zone.y1 >= 4096 || zone.y2 >= 4096) {
		// zone values out of bound
		return;
	}

	if (zone.x1 <= zone.x2) {
		_trigger_zone.x1 = zone.x1;
		_trigger_zone.x2 = zone.x2;
	} else {
		_trigger_zone.x1 = zone.x2;
		_trigger_zone.x2 = zone.x1;
	}
	if (zone.y1 <= zone.y2) {
		_trigger_zone.y1 = zone.y1;
		_trigger_zone.y2 = zone.y2;
	} else {
		_trigger_zone.y1 = zone.y2;
		_trigger_zone.y2 = zone.y1;
	}
}

Camera::trig_zone_t Camera::getTriggerZone(void)
{
	return _trigger_zone;
}

void Camera::externalTrigger(void) {
	if (_state == ST_TRIGGER) {
		_external_trigger = 1;
	}
}

uint8_t Camera::capture(void) {
	if (!_sensor) {
		return 1;
	}

	if (_frame_count >= _frame_buf_size) {
		// no more space in frame buffer
		return 2;
	}

	if (_burst_enable) {
		if (_frame_count + _burst_frames > _frame_buf_size) {
			// no space to store all burst frames in frame buffer
			return 2;
		}
	}

	if (_trigger_enable) {
		_state = ST_TRIGGER;
		if (_trigger_source == TRIG_EXTERNAL) {
			_setupExternalTrigger();
		} else {
			_startCapture(1);
		}
		return 0;
	}

	_startCapture(0);

	return 0;
}

void Camera::abort(void) {
	if (!_sensor || _state == ST_IDLE) {
		return;
	}

	_stopCapture();
}

Frame* Camera::readFrame(void) {
	if (!_sensor || !_frame_buffer || _frame_count == 0 || _state != ST_IDLE) {
		return 0;
	}

	Frame* frame = &_frame_buffer[_frame_read];

	_frame_count--;
	_frame_read++;
	if (_frame_read >= _frame_buf_size) {
		_frame_read = 0;
	}

	return frame;
}

uint16_t Camera::getRemainingFrames(void) {
	return _frame_count;
}

void Camera::_captureLoop(void) {
	uint16_t pixels;

	if (_capture_pending && _sensor->_dataReady()) {
		_capture_pending = 0;
		pixels = _sensor->_readImage(_frame_buffer[_frame_write].pixels);
		if (!pixels) {
			// abort if error reading out pixels
			_stopCapture();
		}
		_commitFrame(_capture_frame_time, pixels);
		_capture_frame++;

		if (!_burst_enable || _capture_frame >= _burst_frames) {
			// last frame, we're done
			_stopCapture();
			return;
		}
	}

	if (!_capture_pending) {
		// start exposure of next frame in burst when time is up
		if (HAL_GetTick() - _capture_frame_time >= _burst_interval) {
			_capture_frame_time = HAL_GetTick();
			_sensor->_exposeImage(_exposure_time);
			_capture_pending = 1;
		}
	}
}
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

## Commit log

2020-10-08 split epc901 camera class into its own library
2020-10-08 add snap.py, reset sensor when opening camera
    [epc901camera.py, snap.py]
2020-10-08 add burst, fix bugs
    [burst.py, epc901camera.py, live.py]
2020-10-09 improved plot, discard first frame in burst
2020-10-10 Optimize SPI transfer (597->746fps)
2020-10-10 add cmd 'transfer last' to read newest frame and discard the rest
2020-10-10 don't clk READ during last ADC conversion
2020-10-11 breakout to shield adapter
    [adapter-shield.kicad_pcb, adapter-shield.sch, epc901-breakout.kicad_pcb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]
2020-10-11 cleanup sheet info
    [adapter-shield.kicad_pcb, adapter-shield.sch, epc901-breakout.kicad_pcb]
2020-10-11 Control shutter with TIM1 timer peripheral
2020-10-11 enable one pulse timer only once
2020-10-13 added fast burst mode, fixed clearing of sensor
    [Camera.cpp, Camera.hpp, EPC901.cpp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]
2020-10-14 save snap csv as a single row, save correct number of frames for burst animation
    [burst.py, snap.py]
2020-10-19 Refactored capture to be async, fixed UART crash
    [App.cpp, Camera.cpp, Camera.hpp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]
2020-10-25 changed pinout to match adapter board
2020-10-26 document breakout board
2020-10-26 add drawing of dimensions, schematics as pdf
    [epc901-breakout.kicad_pcb]
2020-10-27 document adapter board
2020-10-30 fixed clearing of sensor via pins
    [EPC901.cpp]
2020-11-04 rename trigger region to zone, and fix it
    [Camera.cpp, Camera.hpp, burst.py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]
2020-11-04 fix -sx for 2d plot
    [burst.py]
2020-11-09 Add 3D model for spectroscope tube
    [Spectroscope_Tube_180mm.stl]
2020-11-11 Add license information to hardware design files
    [adapter-shield.kicad_pcb, adapter-shield.sch, epc901-breakout.kicad_pcb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]
2020-12-01 Fixed I2C address configuration during init
    [EPC901.cpp]
2021-03-25 rear view of assembled hardware
2023-03-03 update prices of sensor and dev-kit

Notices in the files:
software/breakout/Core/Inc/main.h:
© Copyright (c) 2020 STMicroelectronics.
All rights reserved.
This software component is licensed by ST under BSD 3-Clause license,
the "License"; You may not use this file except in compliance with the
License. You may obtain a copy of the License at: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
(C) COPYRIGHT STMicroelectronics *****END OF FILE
